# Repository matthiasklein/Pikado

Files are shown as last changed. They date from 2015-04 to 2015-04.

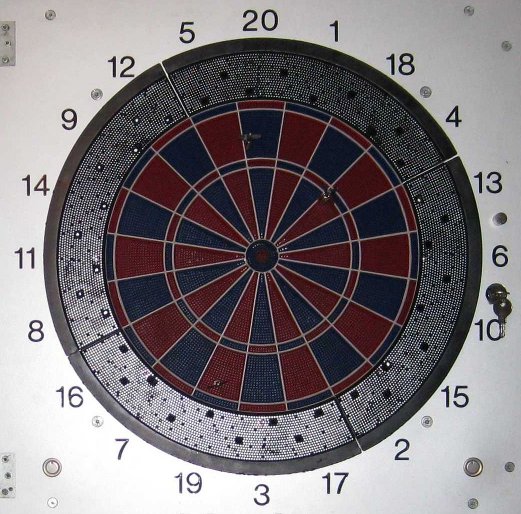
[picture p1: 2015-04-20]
photos/board_v2.jpg

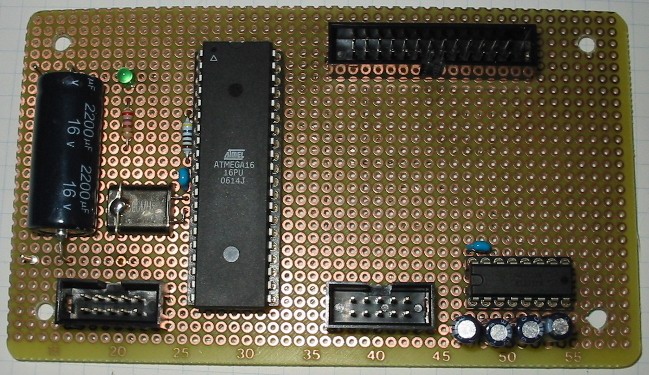
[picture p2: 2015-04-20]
photos/interface_v1_prototype.jpg

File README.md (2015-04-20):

README file for the Pikado project
==================================

What is Pikado ?
----------------
Pikado is the croatian word for darts. This project has the goal to build a PC
based e-dart machine. The project consists of a interface electronic and a GUI
application.

Interface electronic
--------------------
The interface is a PCB which connects an electronic dart board (only the 
switch matrix) and optional some push buttons to the PC. Using that PCB the
GUI application can detect the thrown darts of the players. The PCB uses an
AVR micro-controller and connects via RS232 serial connection to the PC.
I have used the interface successfully with the US232R USB<->RS232 converter
cable from FTDI (FT232R chipset).

Until now I designed two versions of the PCB:
- V1: This is a small universal PCB which can be mounted in cheap home e-dart
      boards. (The normal electronic of the home e-dart board must be removed)
      This PCB can be connected to any switch matrix with a maximum of 
      24 signal lines.

- V2: For my homemade dart machine I searched a switch matrix with a long spare
      part availability. I selected the throwing circle and switch matrix of 
      the dart machines from the NSM-LÖWEN ENTERTAINMENT GmbH.
      => This project has nothing in common with the NSM-LÖWEN ENTERTAINMENT GmbH.
      => I only used their spare parts.
      
      Therefore I designed a new PCB which fits directly to the connector of
      the LÖWEN switch matrix.

My future plans for the PCB:
- Use a vibration sensor to detect darts which hits the catch ring or only the 
  case of the board. (At the moment the player has to press a push-button if
  less than three darts are in the board)
- Use a movement sensor to detect the removal of the darts by the player.
  (At the moment the player has to press a push-button after removing the darts)

Software used for the interface:
- For the schematic and PCB layout:  The freeware version of EAGLE 5.6 <http://cadsoft.de/>
- For the micro-controller software: avr-gcc + avr-libc
- For flashing the micro-controller: avrdude

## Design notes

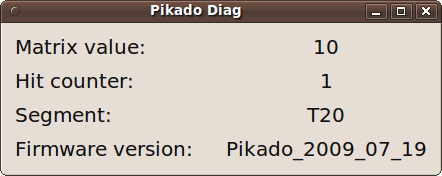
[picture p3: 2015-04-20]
photos/pikado_diag.png

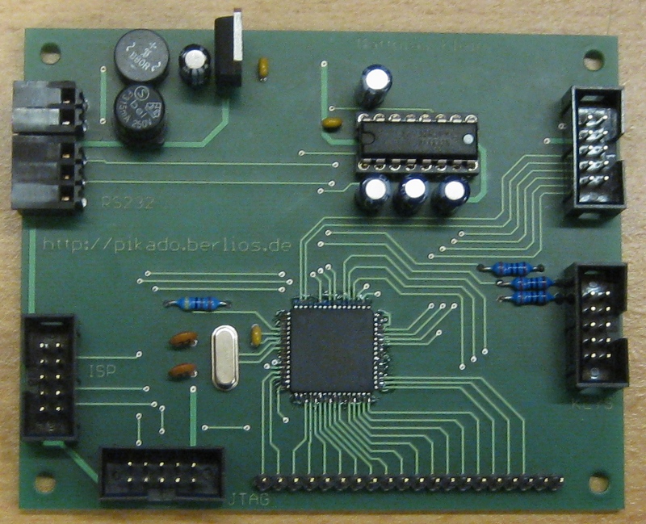
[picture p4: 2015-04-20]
photos/interface_v2.jpg

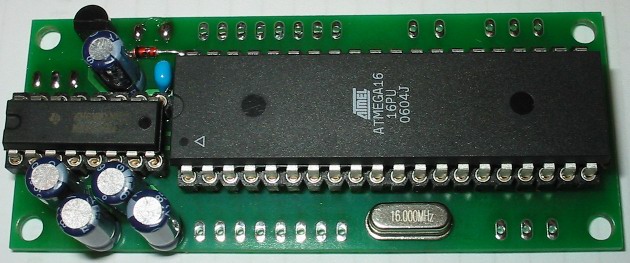
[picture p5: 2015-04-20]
photos/interface_v1.jpg

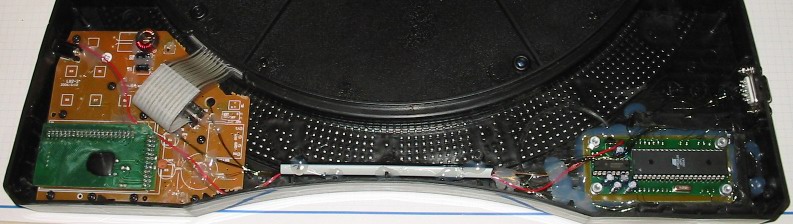
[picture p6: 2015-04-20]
photos/board_v1.jpg

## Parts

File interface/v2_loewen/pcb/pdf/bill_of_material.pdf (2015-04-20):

Quanity | Position | Description | Reichelt order number
1 | B2 | Rectifier | B80C800RUND
1 | F1 | Fuse holder | PL 166600
1 | F1 | Fuse 315mA fast | MINI FLINK 0,315
1 | C7 | Capacitor 47µF 2mm grid | RAD 47/25
1 | IC4 | Voltage regulator 5V | µA 7805
3 | C8, C9, C10 | Capacitor 100nF 2,5mm grid | X7R-2,5 100N
2 | C1, C2 | Capacitor 33pF 2,5mm grid | KERKO 33P
4 | C3, C4, C5, C6 | Capacitor 1µF 2mm grid | RAD 1/63
1 | Q1 | Crystal 16MHz | 16,0000-HC49U-S
1 | R8 | Resitor 4,7 kOhm | Metall 4,70k
3 | R1, R2, R3 | Resitor 270 Ohm | Metall 270
1 | IC1 | Microcontroller | ATMEGA 128-16 TQ
1 | IC2 | RS232 voltage converter | MAX 232 CPE
1 | IC2 | Socket | GS 16P
1 | X5 | Multi-pin connector | SL 1X36G 2,54
4 | X3, X4, X6, X7 | Multi-pin connector | WSL 10G
1 | X1 | RIACON connector | AKL 182-02
1 | X1 | RIACON connector | AKL 169-02
1 | X2 | RIACON connector | AKL 182-03
1 | X2 | RIACON connector | AKL 169-03

## Bill of material

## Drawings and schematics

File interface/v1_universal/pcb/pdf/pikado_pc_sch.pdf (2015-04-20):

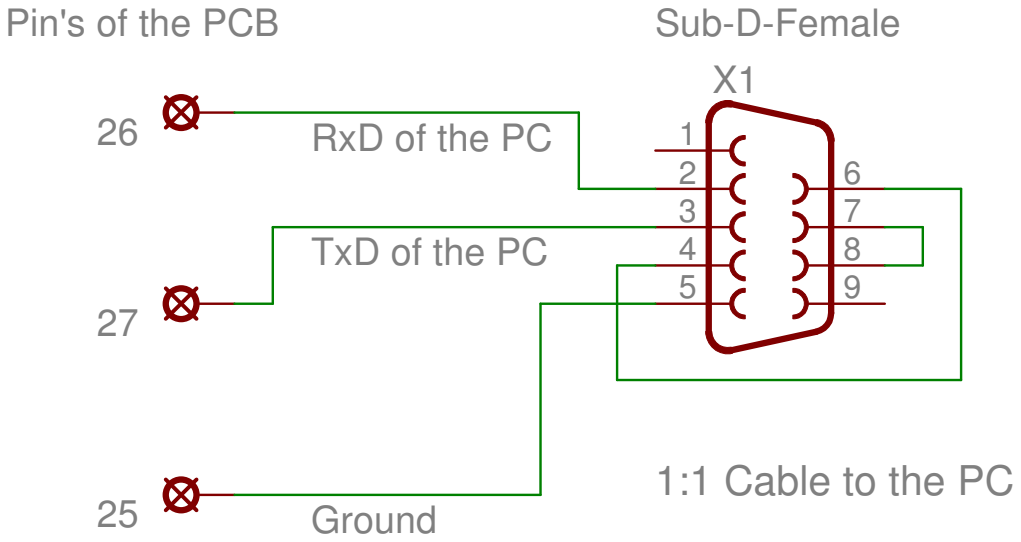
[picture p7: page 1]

RxD of the PC

TxD of the PC

1:1 Cable to the PC

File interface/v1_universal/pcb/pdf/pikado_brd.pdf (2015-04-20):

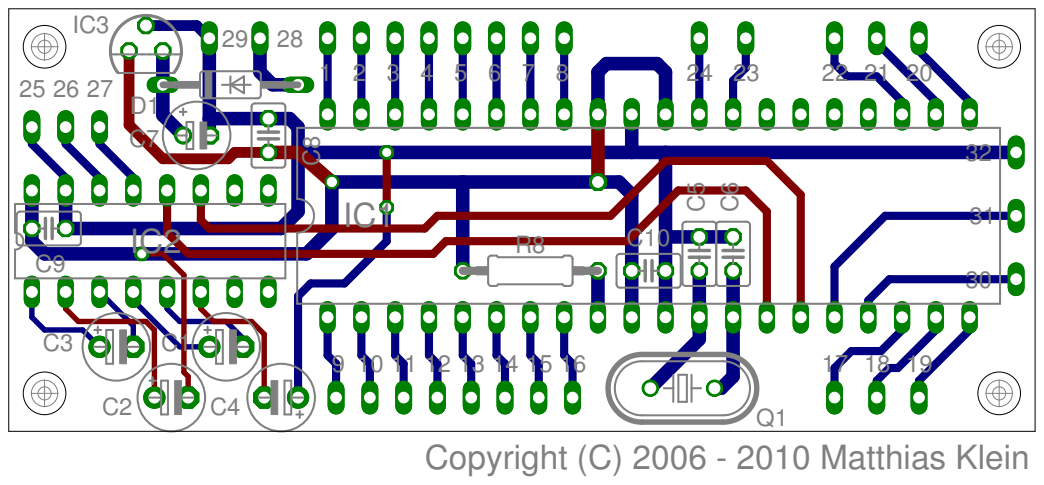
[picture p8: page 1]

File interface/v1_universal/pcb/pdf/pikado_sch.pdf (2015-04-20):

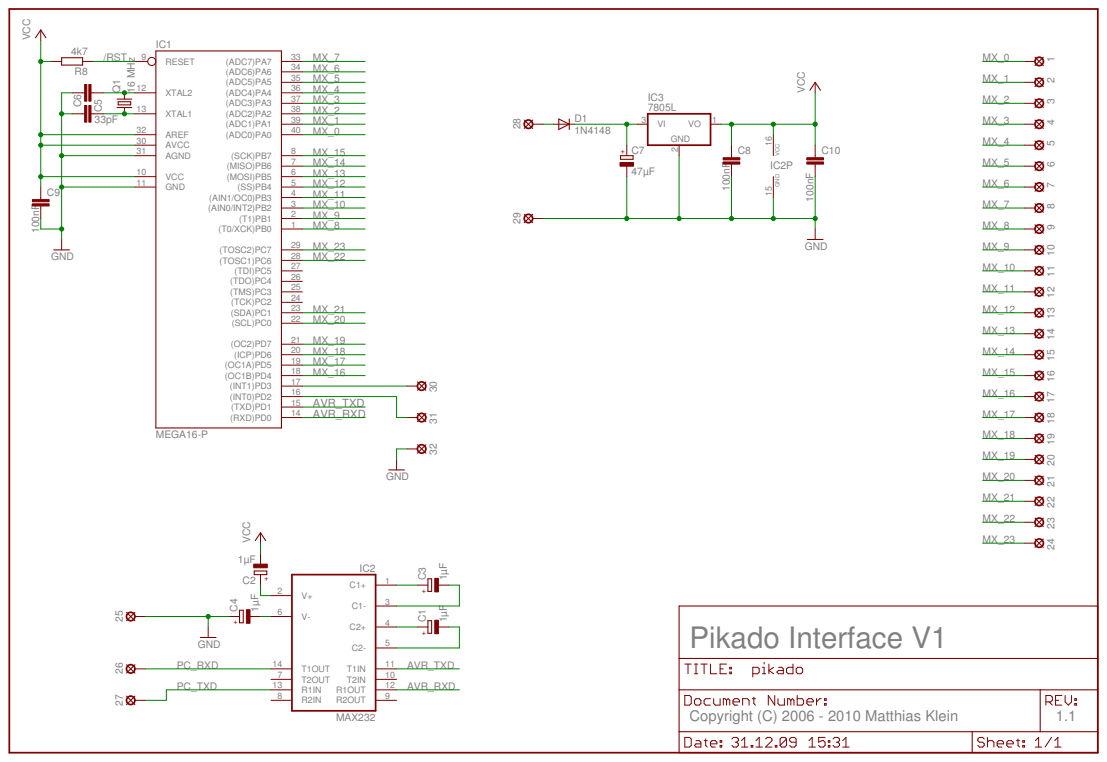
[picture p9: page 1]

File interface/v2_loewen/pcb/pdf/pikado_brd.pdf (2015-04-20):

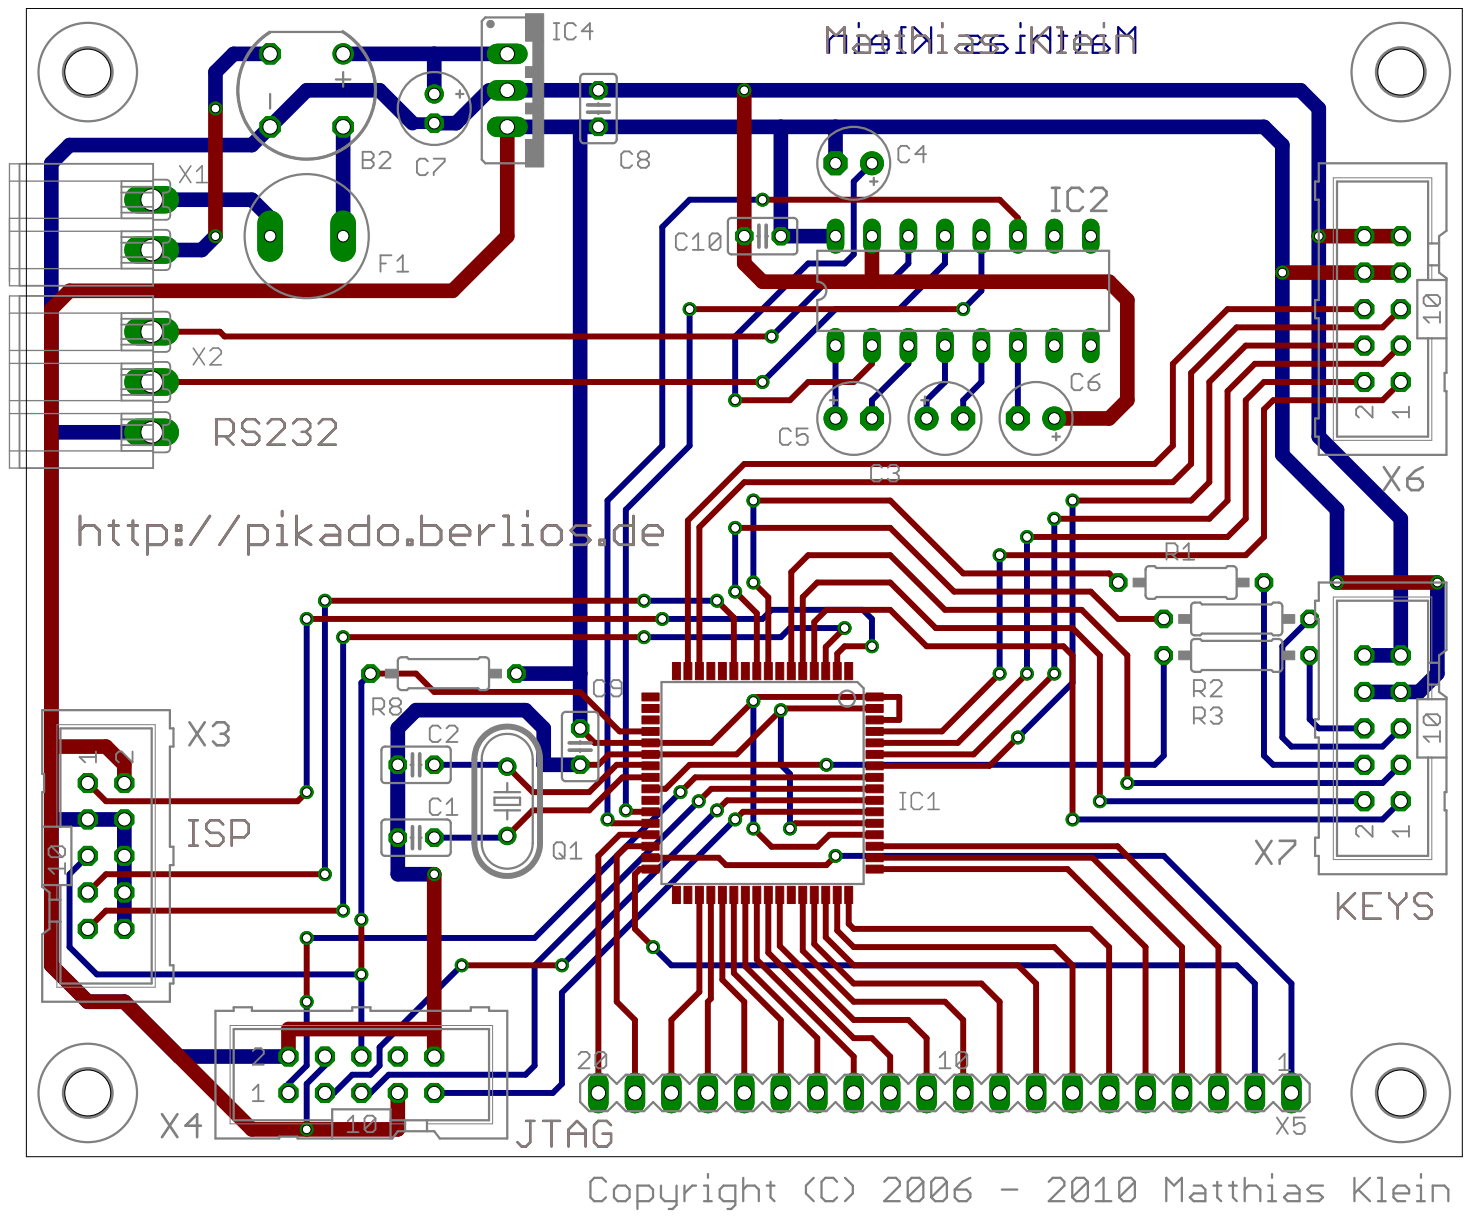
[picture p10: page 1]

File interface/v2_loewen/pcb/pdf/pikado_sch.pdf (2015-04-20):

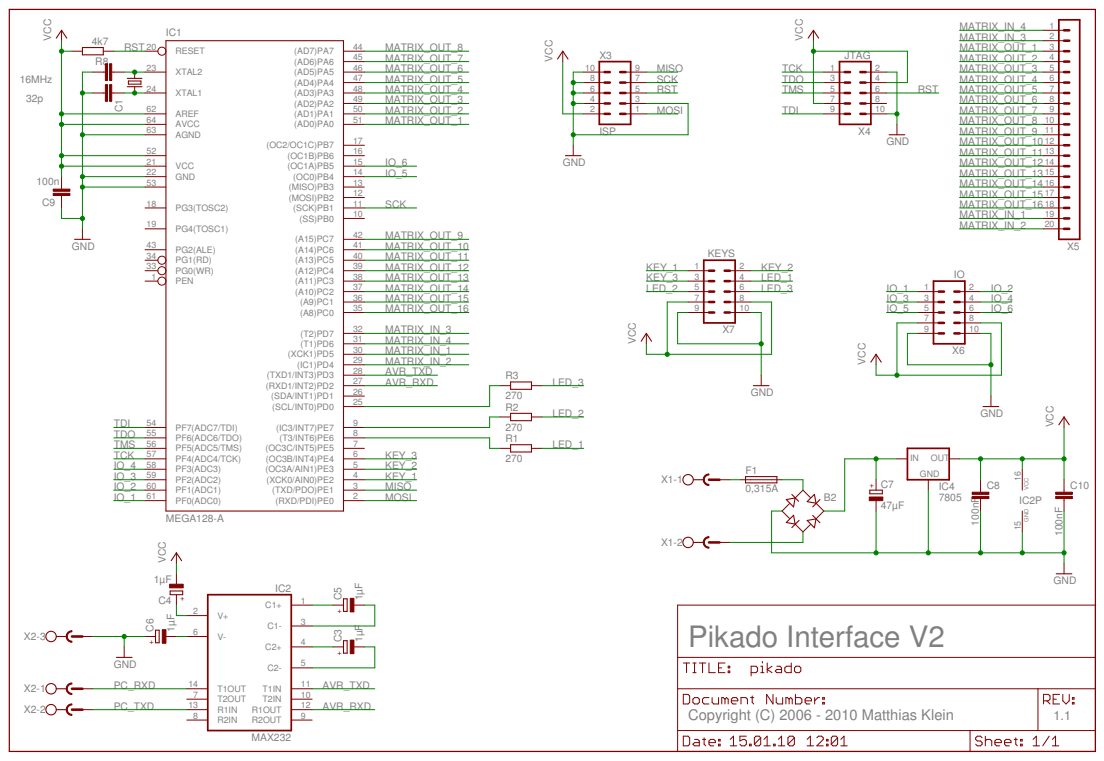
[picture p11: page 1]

21
22

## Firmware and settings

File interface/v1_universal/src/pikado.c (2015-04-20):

/*******************************************************************************
*  Pikado - Interface electronic and GUI for a PC based e-dart machine         *
*  Copyright (C) 2006 - 2010 Matthias Klein <matthias.klein@linux.com>         *
*                                                                              *
*  This file is part of Pikado.                                                *
*                                                                              *
*  Pikado is free software: you can redistribute it and/or modify              *
*  it under the terms of the GNU General Public License as published by        *
*  the Free Software Foundation, either version 3 of the License, or           *
*  (at your option) any later version.                                         *
*                                                                              *
*  Pikado is distributed in the hope that it will be useful,                   *
*  but WITHOUT ANY WARRANTY; without even the implied warranty of              *
*  MERCHANTABILITY or FITNESS FOR A PARTICULAR PURPOSE.  See the               *
*  GNU General Public License for more details.                                *
*                                                                              *
*  You should have received a copy of the GNU General Public License           *
*  along with Pikado.  If not, see <http://www.gnu.org/licenses/>.             *
*******************************************************************************/
#include <avr/io.h>
#include <avr/interrupt.h>
#include <string.h>

typedef unsigned char u08;

u08 SoftwareVersion[] = "Pikado_2006_07_15";

#define TIMER0_RELOAD   205    // 200us @ 16 MHz
#define PC_BAUDRATE     51     // 19200 Baud @ 16MHz

#define MEM_ADR_DDRC    (u08 *) 0x14 + 0x20
#define MEM_ADR_DDRD    (u08 *) 0x11 + 0x20

#define REC_CNT         25     // Number of recordings

// Configuration
volatile u08 OutputCount;     // 1..8

// Data from the Matrix
volatile u08 *MxOutDDR[8];     // Addresses of the DDR-register of the outputs
volatile u08 MxOutVal[8];      // Output values for the outputs

// Memory for the recordings
volatile u08 MxData[REC_CNT][8][3];
volatile u08 MxRecStart, MxRecFinish;

// Memory for the analysis
u08 MxCount[8][3][8];          // [output][input-byte][input-bit]

void config_outputs(void)
{
  switch(OutputCount)
  {
  case 4:
    DDRD  &= 0x0F;        // Inputs:                  PD4..PD7
    PORTD |= 0xF0;        // Internal pull-up enable: PD4..PD7
    break;
  case 5:
    DDRD  |= 0x80;        // Output:                  PD7
    DDRD  &= 0x8F;        // Inputs:                  PD4..PD6
    PORTD &= 0x7F;        // Tri-state (Hi-Z):        PD7
    PORTD |= 0x70;        // Internal pull-up enable: PD4..PD6
    break;
  case 6:
    DDRD  |= 0xC0;        // Output:                  PD6, PD7
    DDRD  &= 0xCF;        // Inputs:                  PD4, PD5
    PORTD &= 0x3F;        // Tri-state (Hi-Z):        PD6, PD7
    PORTD |= 0x30;        // Internal pull-up enable: PD4, PD5
    break;
  case 7:
    DDRD  |= 0xE0;        // Output:                  PD5..PD7
    DDRD  &= 0xEF;        // Inputs:                  PD4
    PORTD &= 0x1F;        // Tri-state (Hi-Z):        PD5..PD7
    PORTD |= 0x10;        // Internal pull-up enable: PD4
    break;
  case 8:
    DDRD  |= 0xF0;        // Output:                  PD4..PD7
    PORTD &= 0x0F;        // Tri-state (Hi-Z):        PD4..PD7
    break;
  }
}

void init(void)
{
  OutputCount = 4;

  memset(MxData, 0, sizeof(MxData));
  MxRecStart   = 0;
  MxRecFinish  = 0;

  MxOutDDR[0] = MEM_ADR_DDRC;
  MxOutVal[0] = 1<<PC7;

  MxOutDDR[1] = MEM_ADR_DDRC;
  MxOutVal[1] = 1<<PC6;

  MxOutDDR[2] = MEM_ADR_DDRC;
  MxOutVal[2] = 1<<PC1;

  MxOutDDR[3] = MEM_ADR_DDRC;
  MxOutVal[3] = 1<<PC0;

  MxOutDDR[4] = MEM_ADR_DDRD;
  MxOutVal[4] = 1<<PD7;

  MxOutDDR[5] = MEM_ADR_DDRD;
  MxOutVal[5] = 1<<PD6;

  MxOutDDR[6] = MEM_ADR_DDRD;
  MxOutVal[6] = 1<<PD5;

  MxOutDDR[7] = MEM_ADR_DDRD;
  MxOutVal[7] = 1<<PD4;

  // USART: Baudrate
  UBRRH =  (u08) (PC_BAUDRATE >> 8);
  UBRRL =  (u08) PC_BAUDRATE;
  
  // USART: Sender, receiver und receiver-interrupt enable
  UCSRB =  (1<<RXEN) | (1<<TXEN) | (1<<RXCIE);

  // USART: Dataformat: 8data, 1stop bit
  UCSRC =  (1<<URSEL) | (1<<UCSZ1) | (1<<UCSZ0);

  TIFR  |= 1<<TOV0;               // Clear timer 0 overflow flag
  TIMSK |= 1<<TOIE0;              // Timer 0 overflow interrupt enable
  TCNT0 =  TIMER0_RELOAD;
  TCCR0 =  (1<<CS01) | (1<<CS00); // Timer 0 run: prescaler 64

  TIFR  |= 1<<TOV2;               // Clear timer 2 overflow flag
  TCNT2 =  0;
  TCCR2 =  0x07;                  // Timer 2 run: prescaler 1024

  DDRA  =  0x00;                  // Inputs
  PORTA =  0xFF;                  // Internal pull-up enable

  DDRB  =  0x00;                  // Inputs
  PORTB =  0xFF;                  // Internal pull-up enable

  DDRC  &= 0x3C;                  // Outputs:          PC0, PC1, PC6, PC7
  PORTC &= 0x3C;                  // Tri-state (Hi-Z): PC0, PC1, PC6, PC7

  // For the two push-buttons
  DDRD  &= 0xF3;                  // Inputs:                  PD2..PD3
  PORTD |= 0x0C;                  // Internal pull-up enable: PD2..PD3

  config_outputs();
  sei();                          // Global interrupt enable
}

ISR(TIMER0_OVF_vect)
{
  TCNT0 = TIMER0_RELOAD;

  u08 nOut, i, In[3];
  static u08 RecIndex = 0;

  if(MxRecFinish != 0)
    return;
  
  for(nOut=0; nOut<OutputCount; nOut++)
  {
    // Readout of the matrix
    *MxOutDDR[nOut] |= MxOutVal[nOut];
    asm("nop");
    asm("nop");
    asm("nop");
    asm("nop");
    
    In[0] = ~PINA;
    In[1] = ~PINB;
    In[2] = ~PIND;
    In[2] >>= 4;

    *MxOutDDR[nOut] &= ~MxOutVal[nOut];

    // Mask-out of the unused inputs
    if      (OutputCount == 5)
      In[2] &= 0x07;
    else if (OutputCount == 6)
      In[2] &= 0x03;    
    else if (OutputCount == 7)
      In[2] &= 0x01;    
    else if (OutputCount == 8)
      In[2] &= 0x00;

    if(MxRecStart == 0)
    {
      // Search for a hit
      for(i=0; i<3; i++)
      {
        if(In[i] != 0)
          MxRecStart = 0xFF;
      }
    }
    else
    {
      // Recording ...
      for(i=0; i<3; i++)
        MxData[RecIndex][nOut][i] = In[i];
    }
  }

  if(MxRecStart != 0)
  {
    RecIndex++;

    if(RecIndex == REC_CNT)
    {
      RecIndex    = 0;
      MxRecStart  = 0;
      MxRecFinish = 0xFF;
    }
  }
}

void pc_send(u08 *data, u08 len)
{
  u08 i;
  
  for(i=0; i<len; i++)
  {
    while (!(UCSRA & (1<<UDRE))); // wait until the dataregister is ready
    UDR = data[i];
  }
}

ISR(USART_RXC_vect)
{
  u08 c = UDR;

  if(c == 0x00)    // Connection test
  {
    c = 0xFF;
    pc_send(&c, 1);
  }
  else if((c >= 0x04) && (c <= 0x08))    // Set the output count
  {
    OutputCount = c;
    config_outputs();
    c = 0x00;
    pc_send(&c, 1);
  }
  else if(c == 0x10)    // Get the output count
  {
    c = OutputCount;
    pc_send(&c, 1);
  }
  else if(c == 0x11)    // Send the software version
  {
    pc_send(SoftwareVersion, strlen((char *) SoftwareVersion) + 1);
  }
}

void delay_ms(unsigned long ms) // max. 4 seconds
{
  
  TIFR   |= 1<<TOV1;                    // Clear timer 1 overflow flag
  ms = 0xFFFF - ((ms * 1000) / 64);
  TCNT1  =  (unsigned int) ms;
  TCCR1B =  (1<<CS12) | (1<<CS10);      // Timer 1 run: prescaler 1024

  while(!(TIFR & 1<<TOV1));             // Wait until the timer overflows

  TCCR1B =  0;                          // Timer 1 stop
}

int main(void)
{
  // For the analysis of the matrix recordings
  u08 nRec, nOut, nIn, BitMask, BitPos;
  u08 HitVal, nOutHit, nInHit, nBitHit;
  u08 SegmentNr;

  // Debouncing of the push-buttons
  u08 tmp;
  u08 key_state = 0;
  u08 key_press = 0;
  u08 ct0       = 0;
  u08 ct1       = 0;

  init();
  
  while(1)
  {
    // Push-button debouncing: timer2 overflows all 16,384ms
    if(TIFR & 1<<TOV2)
    {
      TIFR |= 1<<TOV2;              // Clear timer 2 overflow flag

      tmp = key_state ^ ~PIND;      // Key changed ?
      ct0 = ~( ct0 & tmp );         // Reset or count ct0
      ct1 = (ct0 ^ ct1) & tmp;      // Reset or count ct1
      tmp &= ct0 & ct1;             // Count until roll over 
      key_state ^= tmp;             // Then toggle debounced state
      key_press |= key_state & tmp; // 0->1: key pressing detect

      // 1. Push-button
      if(key_press & 0x04)
      {
        SegmentNr = 0xFE;
        pc_send(&SegmentNr, 1);

        key_press &= 0xFB;
      }

      // 2. Push-button
      if(key_press & 0x08)
      {
        SegmentNr = 0xFF;
        pc_send(&SegmentNr, 1);

        key_press &= 0xF7;
      }
    }

    // Dart recognized and data recorded
    if(MxRecFinish != 0)
    {
      memset(MxCount, 0, sizeof(MxCount));

      // Counting of the high-pulses
      for(nRec=0; nRec<REC_CNT; nRec++)
      {
        for(nOut=0; nOut<OutputCount; nOut++)
        {
          for(nIn=0; nIn<3; nIn++)
          {
            BitPos = 0;
            for(BitMask=1; BitMask!=0; BitMask<<=1)
            {
              BitPos++;
              
              // Contact was closed
              if(MxData[nRec][nOut][nIn] & BitMask)
              {
                MxCount[nOut][nIn][BitPos]++;
              }
            }
          }
        }
      }

      // Search the highest count
      HitVal  = 0;
      nOutHit = 0;
      nInHit  = 0;
      nBitHit = 0;
      for(nOut=0; nOut<OutputCount; nOut++)
      {
        for(nIn=0; nIn<3; nIn++)
        {
          for(BitPos=0; BitPos<8; BitPos++)
          {
            if(MxCount[nOut][nIn][BitPos] > HitVal)
            {
              HitVal  = MxCount[nOut][nIn][BitPos];
              
              nOutHit = nOut;
              nInHit  = nIn;
              nBitHit = BitPos;
            }
          }
        }
      }

      // Special version for Claus with "HitVal >= 4"
      if(HitVal >= 2)
      {
        // Send the SegmentNr to the PC
        SegmentNr = nBitHit + (nInHit * 8) + (nOutHit * 20);
        pc_send(&SegmentNr, 1);

        // Wait for 200ms
        delay_ms(200);
      }

      // Enable for the next recording
      MxRecFinish = 0x0;
    }
  }
}
